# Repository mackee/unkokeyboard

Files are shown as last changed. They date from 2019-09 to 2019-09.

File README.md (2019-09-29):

# Cool Poop Keyboard

The Cool Poop Keyboard is a too-small keyboard.



This keyboard has only 4 keys and 4 full-color LEDs.

It uses an ATTiny84 with [micronucleus](https://github.com/micronucleus/mirconucleus) firmware.

This product made for distributing at [The Techbook fest 7th](https://techbookfest.org/event/tbf07).

Following japanese text is a build guide for customer.

# かっこいいうんこキーボード

この文章は技術書典7などで頒布した「かっこいいうんこキーボード」の取扱説明書です。

## この文章で知れること

- 「かっこいいうんこキーボード」の組み立て方
- 「かっこいいうんこキーボード」のファームウェアのカスタマイズ方法

## 組み立て方

### 部品


|名前|数|備考|
|:---|:---|---|
|PCB|1枚||
|プレート|1枚||
|キースイッチ|4個|赤 or 白 or 茶が4個入っています|
|キーキャップ|4個||
|スペーサー|4個||

### 組み立て
1. PCBにスペーサーを取り付ける。


2. プレートを取り付けて、裏返す。


3. キースイッチを付ける。


4. キーキャップを付けて完成。


## ファームウェアのカスタマイズ方法

### 必要なもの

- [PlatformIO](https://platformio.org/)
- Windowsの場合は[Digisparkのドライバー](https://github.com/digistump/DigistumpArduino/releases/download/1.6.7/Digistump.Drivers.zip)のインストールが必要です
  - また、`make`および`patch`が使える環境が必要です

### ファームウェアの書き込み手順

#### 1. このリポジトリのダウンロード

`git clone`やzipファイルのdownload linkからこのリポジトリのソースコードをダウンロードします。

#### 2. 書き込み環境のセットアップ

`make`コマンドを実行できるCLI環境で1でダウンロードし、展開したディレクトリに移動します。そして、そのディレクトリで以下のコマンドを実行します。

```console
$ make init
```

途中にコンパイルエラーが出ますが、その後にコンパイルエラーを解消するためのパッチが自動で適用されます。

#### 3. ファームウェアの書き込み

以下のコマンドで、「かっこいいうんこキーボード」へのファームウェアの書き込みが実行されます。

```console
$ make upload
```

`> Please plug in the device ...` というメッセージが表示された、「かっこいいうんこキーボード」をUSBケーブルで接続してください。もし、接続したまま実行した場合は、一度抜いてからもう一度挿してください。

`>> Micronucleus done. Thank you!` というメッセージが表示されたら成功です。

### キーのカスタマイズ

キー配置の情報は、`src/Keyboard.ino`に記述されています。

それぞれのキーを`A`, `B`, `C`, `D`に変更する場合は、

```diff
--- a/src/Keyboard.ino
+++ b/src/Keyboard.ino
@@ -8,7 +8,7 @@ WS2812 LED(NEOPIXELS_NUM);
 cRGB value;

 uint8_t keys[] = {9, 8, 7, 3};
-byte keymaps[] = {KEY_U, KEY_N, KEY_K, KEY_O};
+byte keymaps[] = {KEY_A, KEY_B, KEY_C, KEY_D};

 void setup() {
   LED.setOutput(NEOPIXEL_PIN);
```

というように変更し、保存した後に`make upload`を実行して書き込みます。

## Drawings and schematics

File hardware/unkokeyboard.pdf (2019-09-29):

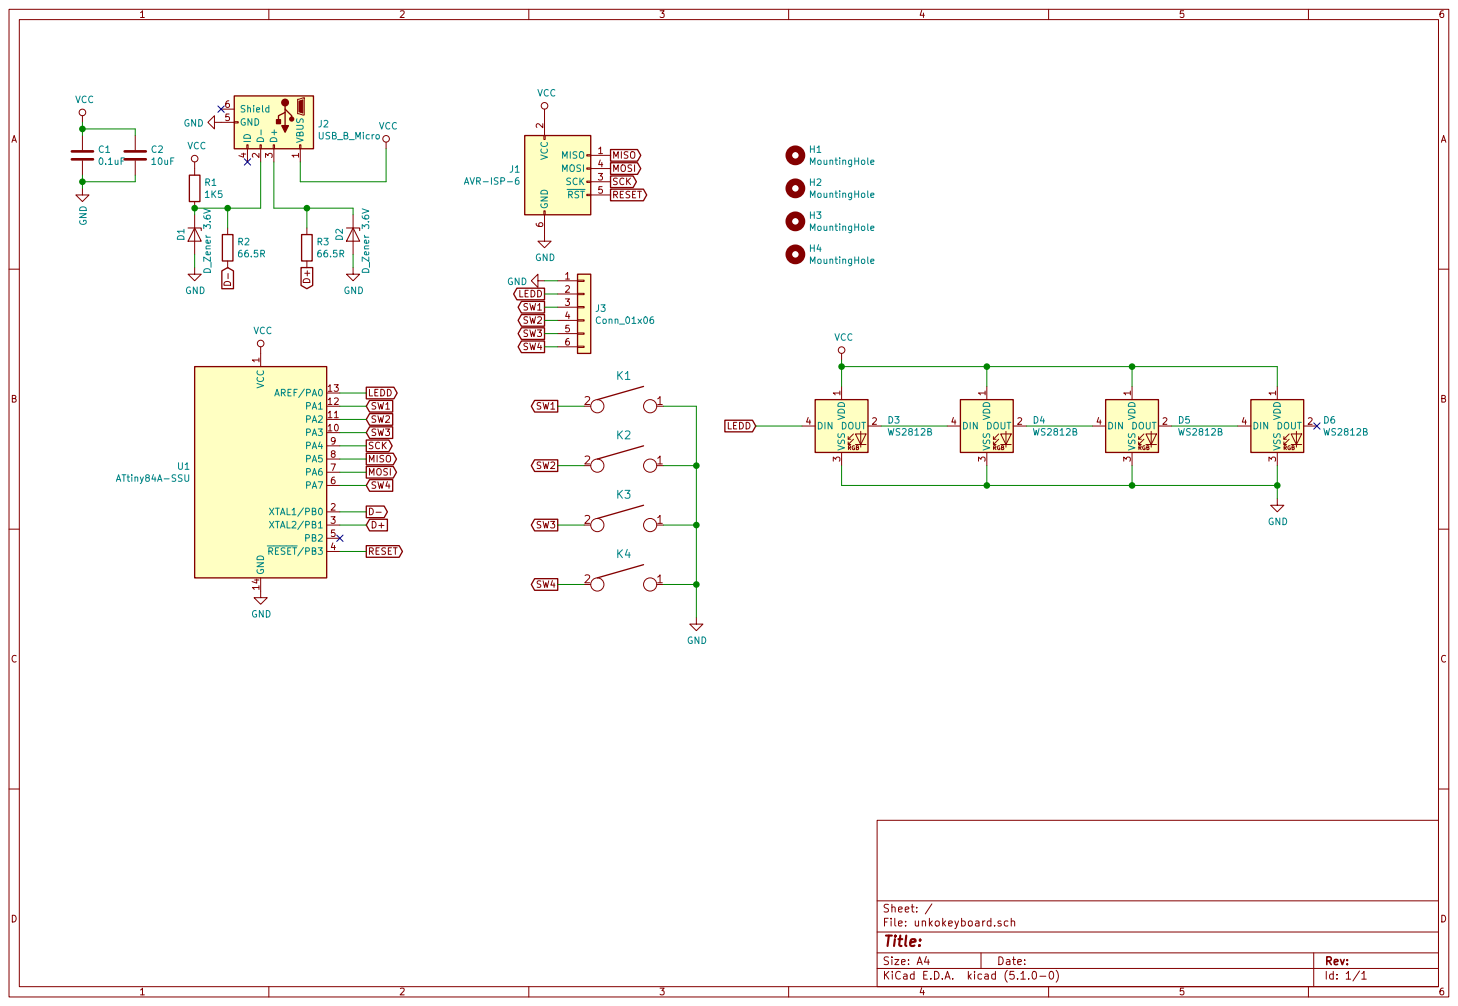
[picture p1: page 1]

RESET SCK MISO MOSI VBUS

2 SCK 3 MOSI 4 RST 5 GND

1 PA3 10 PA2 11 PA1 12 AREF/PA0 13 GND 14 XTAL1/PB0 2 XTAL2/PB1 3 RESET/PB3 4 PB2 5 PA7 6 PA6 7 PA5 8 PA4 9 U1 ATtiny84A-SSU

File: unkokeyboard.sch Sheet: / VCC

SCK MOSI RESET GND

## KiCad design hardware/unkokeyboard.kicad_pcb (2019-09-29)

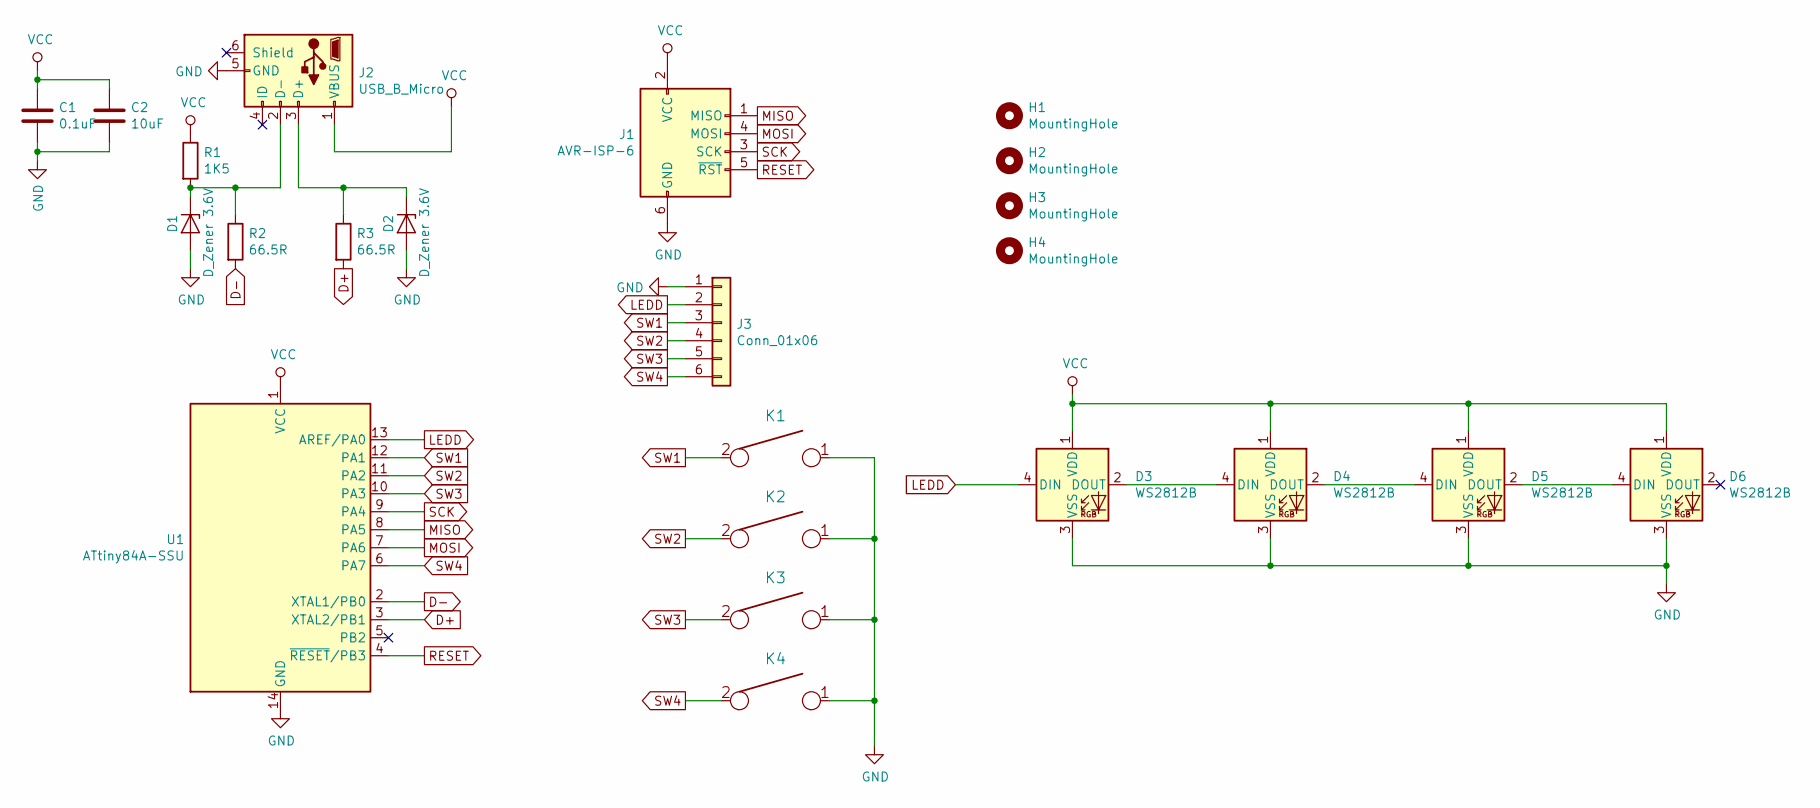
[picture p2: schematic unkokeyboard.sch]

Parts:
C1: 0.1uF; C_1608
C2: 10uF; C_1608
D1, D2: D_Zener 3.6V; D_SOD-323_HandSoldering
D3, D4, D5, D6: WS2812B; WS2812B-2020
H1, H2, H3, H4: MountingHole; MountingHole_2.5mm
J1: AVR-ISP-6; PinHeader_1x06_P2.54mm_Vertical
J2: USB_B_Micro; USB_microB
J3: Conn_01x06; PinHeader_1x06_P2.54mm_Vertical
K1, K2, K3, K4: KEYSW; PG1350_socket
R1: 1K5; R_0603_HandSoldering
R2, R3: 66.5R; R_0603_HandSoldering
U1: ATtiny84A-SSU; SOIC-14_3.9x8.7mm_Pitch1.27mm

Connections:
D+: R3.2, U1.3 (XTAL2/PB1)
D-: R2.2, U1.2 (XTAL1/PB0)
GND: C1.2, C2.2, D1.2 (A), D2.2 (A), D3.3 (VSS), D4.3 (VSS), D5.3 (VSS), D6.3 (VSS), J1.6 (GND), J2.5 (GND), J3.1, K1.1, K2.1, K3.1, K4.1, U1.14 (GND)
LEDD: D3.4 (DIN), J3.2, U1.13 (AREF/PA0)
MISO: J1.1 (MISO), U1.8 (PA5)
MOSI: J1.4 (MOSI), U1.7 (PA6)
unnamed: D1.1 (K), J2.2 (D-), R1.2, R2.1
unnamed: D2.1 (K), J2.3 (D+), R3.1
unnamed: D3.2 (DOUT), D4.4 (DIN)
unnamed: D4.2 (DOUT), D5.4 (DIN)
unnamed: D5.2 (DOUT), D6.4 (DIN)
RESET: J1.5 (~RST), U1.4 (~RESET~/PB3)
SCK: J1.3 (SCK), U1.9 (PA4)
SW1: J3.3, K1.2, U1.12 (PA1)
SW2: J3.4, K2.2, U1.11 (PA2)
SW3: J3.5, K3.2, U1.10 (PA3)
SW4: J3.6, K4.2, U1.6 (PA7)
VCC: C1.1, C2.1, D3.1 (VDD), D4.1 (VDD), D5.1 (VDD), D6.1 (VDD), J1.2 (VCC), J2.1 (VBUS), R1.1, U1.1 (VCC)

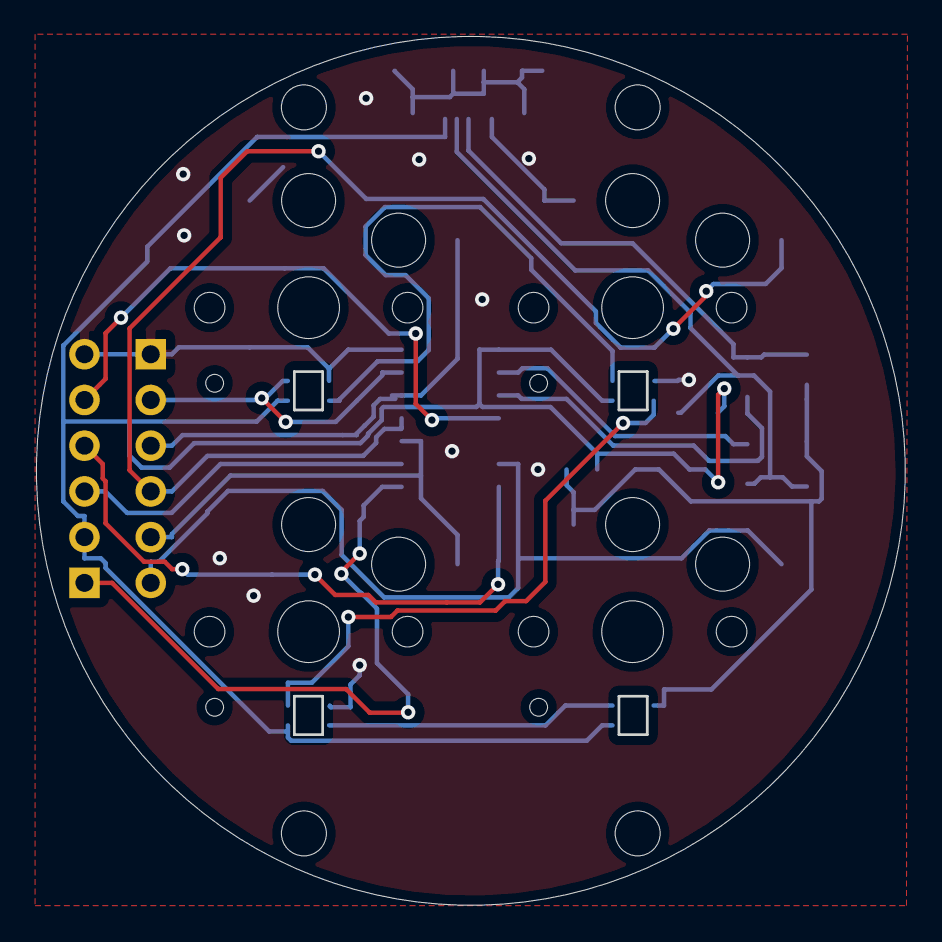
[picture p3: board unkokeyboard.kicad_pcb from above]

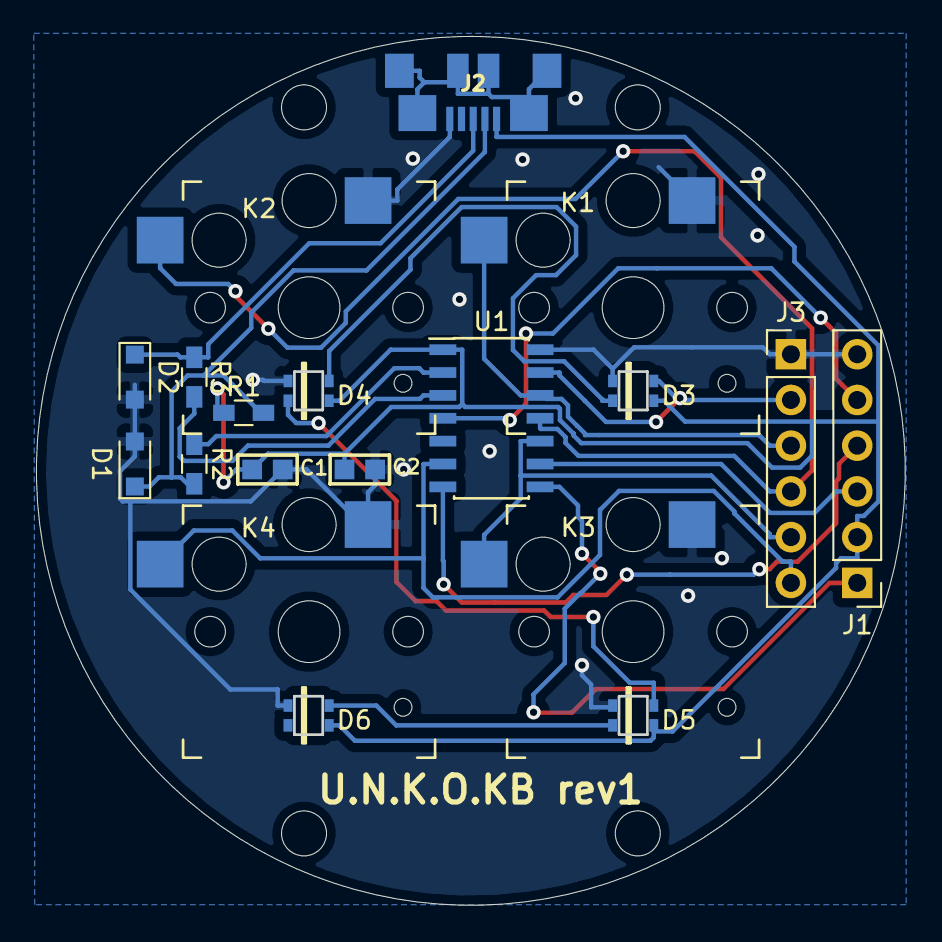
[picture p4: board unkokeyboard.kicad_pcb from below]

Board: 2 copper layers, 48.3 x 48.3 mm, 23 parts (11 on the bottom side), 18 nets.

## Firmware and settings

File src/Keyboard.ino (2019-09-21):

#include "DigiKeyboard.h"
#include "constants.h"

#define USE_HSV
#include <WS2812.h>

WS2812 LED(NEOPIXELS_NUM);
cRGB value;

uint8_t keys[] = {9, 8, 7, 3};
byte keymaps[] = {KEY_U, KEY_N, KEY_K, KEY_O};

void setup() {
  LED.setOutput(NEOPIXEL_PIN);

  for(int i=0;i<NEOPIXELS_NUM;i++) {
    cRGB red = { 64, 0, 0 };
    LED.set_crgb_at(i, red);
  }
  LED.sync();
  delay(500);

  for(int i=0;i<NEOPIXELS_NUM;i++) {
    cRGB green = { 0, 64, 0 };
    LED.set_crgb_at(i, green);
  }
  LED.sync();
  delay(500);

  for(int i=0;i<NEOPIXELS_NUM;i++) {
    cRGB blue = { 0, 0, 64 };
    LED.set_crgb_at(i, blue);
  }
  LED.sync();
  delay(500);

  for(int i=0;i<NEOPIXELS_NUM;i++) {
    cRGB black = { 0, 0, 0 };
    LED.set_crgb_at(i, black);
  }
  LED.sync();
  delay(500);

  for(int i=0;i<KEYS;i++) {
    pinMode(keys[i], INPUT);
    digitalWrite(keys[i], HIGH);
  }
}

void loop() {
  DigiKeyboard.sendKeyStroke(0);

  for(int i=0;i<KEYS;i++) {
    if (digitalRead(keys[i]) == LOW) {
      DigiKeyboard.sendKeyStroke(keymaps[i]);
    }
  }

  showLed();
  DigiKeyboard.delay(100);
}

int h = 0;
int sat = 255;
int val = 255;

void showLed() {
  h += 10;
  h %= 360;

  for(int i=0;i<NEOPIXELS_NUM;i++) {
    cRGB value;
    int hv = (h + (i * 45)) % 360;
    value.SetHSV(hv, sat, 127);
    LED.set_crgb_at(i, value);
  }
  LED.sync();
}

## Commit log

2019-09-21 組み立て方追加
2019-09-29 add pcb
    [panelize.kicad_pcb, unkokeyboard.dsn, unkokeyboard.kicad_pcb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]
